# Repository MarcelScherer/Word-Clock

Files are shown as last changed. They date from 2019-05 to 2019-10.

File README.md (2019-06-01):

# Word-Clock with Android App for color changing (WIP)

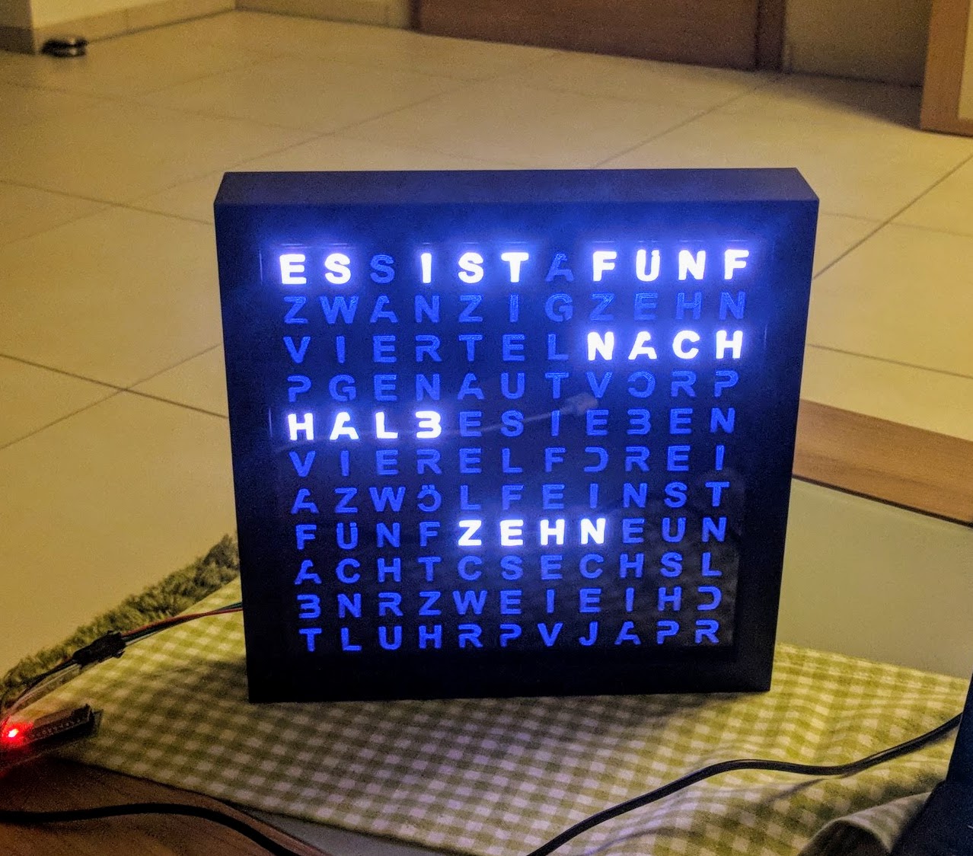
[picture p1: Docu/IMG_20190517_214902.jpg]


in addition, the following external sources are used in this project ... <br>
[NTPClinet for get actual time](https://github.com/arduino-libraries/NTPClient) <br>
[RTClib for offline function](https://github.com/adafruit/RTClib) <br>
[NeoPixelBus for control ws2812b strip](https://github.com/Makuna/NeoPixelBus) <br>
letterboxes.scad (I don't know the original link, sorry ...)

# Hardware

First you have to print the [STL files](https://github.com/MarcelScherer/Word-Clock/tree/master/Hardware) on a 3D printer. If you want to adjust the size, you can also create your own STL files with the help of the [script](https://github.com/MarcelScherer/Word-Clock/blob/master/Hardware/letterboxes.scad) and openSCAD. <br>
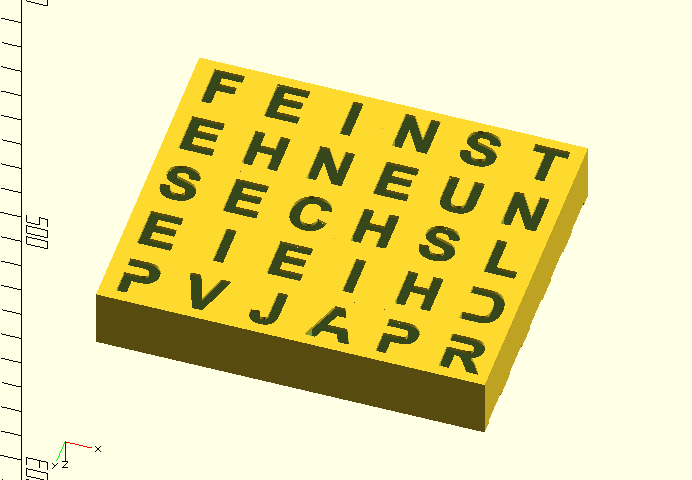
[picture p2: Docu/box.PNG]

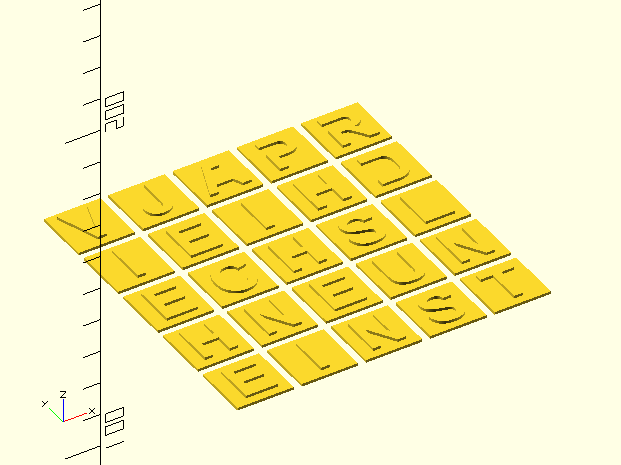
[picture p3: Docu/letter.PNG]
 <br>
<br>
After Printing the boxes and letters ... <br>
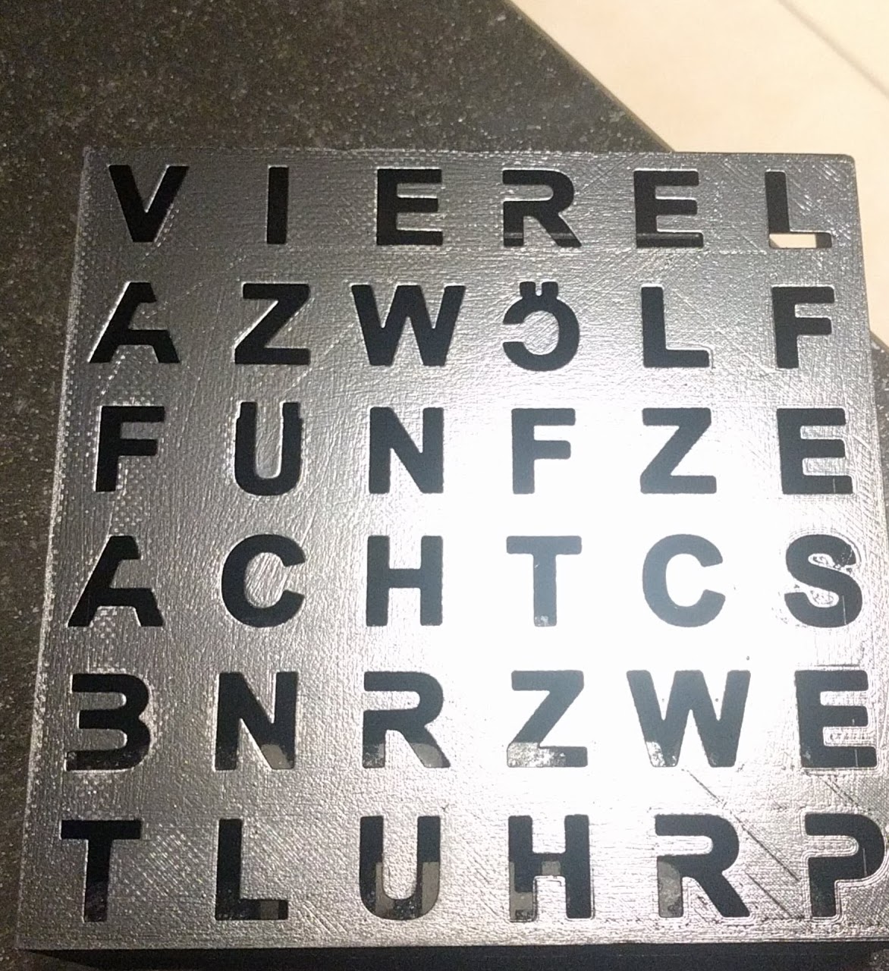
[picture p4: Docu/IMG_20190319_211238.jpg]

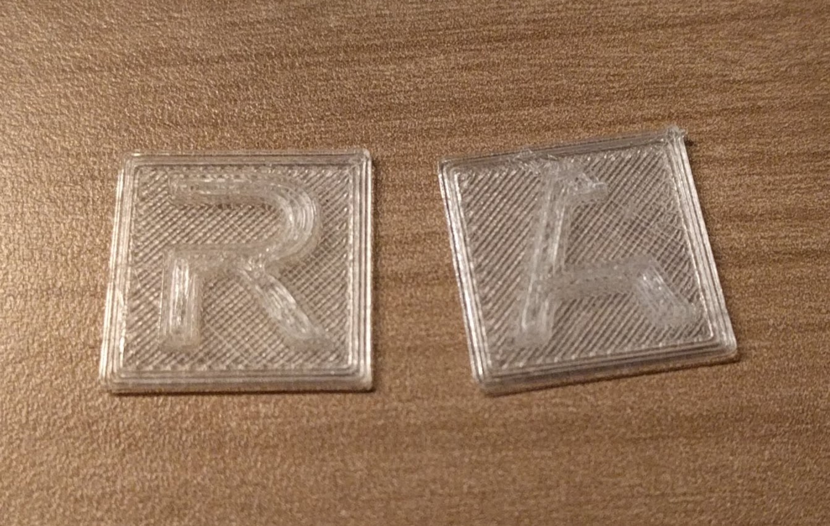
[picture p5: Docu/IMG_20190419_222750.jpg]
  <br>

... then you have to put the letters in the boxes.  <br>
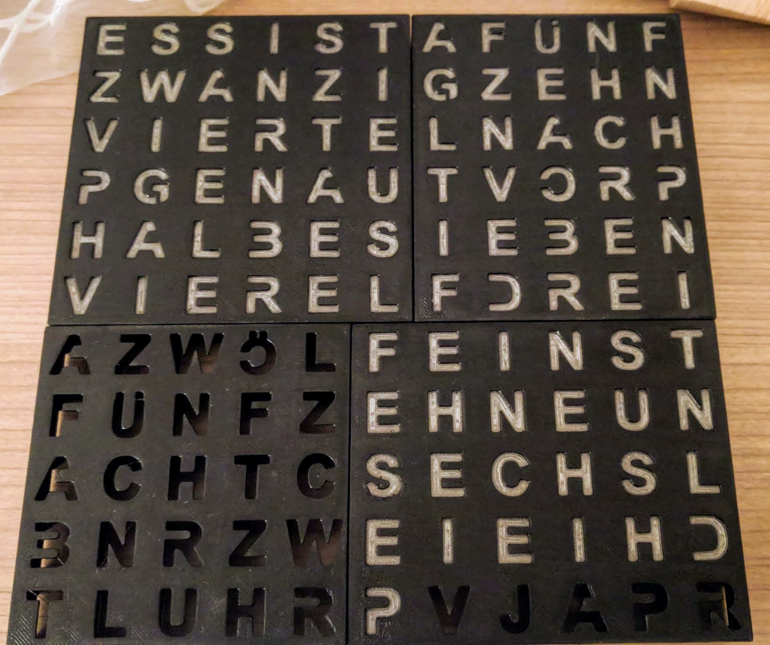
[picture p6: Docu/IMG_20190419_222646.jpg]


After that you have to fix the led ws2812b stripes ... <br>
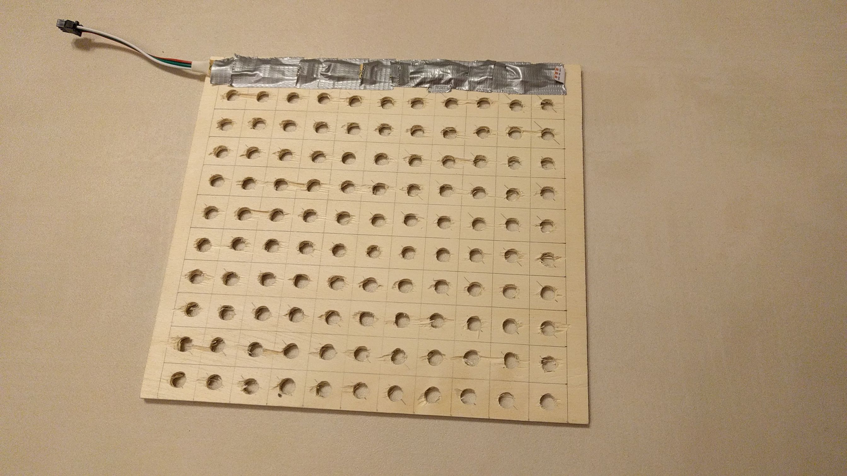
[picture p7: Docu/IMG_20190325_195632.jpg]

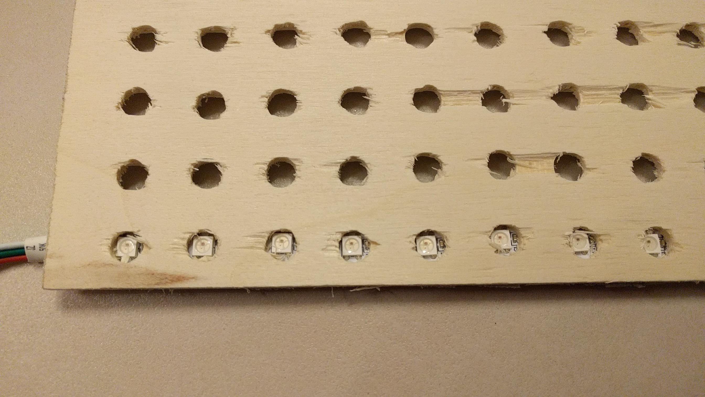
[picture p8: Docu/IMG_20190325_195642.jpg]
  <br>

# Software

You have to compile and flash the sorce (I do it with Visual Studio Code) an an ESP32. For ESP8266 you have to change small things like led pin, NeoPixelBus definition, and so on ...  You can change the pinning for the led-strip in the cfg.h file. I use the pinning ... <br>

| Pin | LED-Strip | Color | 
|---|:---:|---|
| P15 |  Led Pin | green |
| GND |  Ground | white |
| 5V |  Power Supply | red |

| Pin | RTC | Color | 
|---|:---:|---|
| P21 |  SDA | green |
| P22 |  Ground | yellow|
| 5V |  Power Supply | red |
| GND |  GND | blue  |

you can/shold config also in the cfg.h file ... <br>

| define | function | 
|---|---|
|INTERRUPT_PRESCALER | 1000.000 ticks per second |
| | depend on board |
|INTERRUPT_TICK | how many ticks to next interrupt |
|WIFIPWD | wifi password |
|WLAN_SSID | wifi ssid |
|UPDATE_TIME_VAL | ntc update time interval in hours |
|USE_RTC | if you use a RTC or not true/false |
|DEBUG | if you activate debug information |
| | over seral output true/false |
|LED_PIN | Pin for led strip |
|NUM_OF_PIXEL | number of led pixel 121 (11 * 11) |
|MAX_BRIGHTNESS_ON | muximum brightness for led's where on |
|MAX_BRIGHTNESS_OFF  | muximum brightness for led's where off|
|TIME_DISPLAY_OFF | time for display off |
|TIME_DISPLAY_ON | time for display on |

if TIME_DISPLAY_OFF and TIME_DISPLAY_ON are same, the leds are allways on <br>

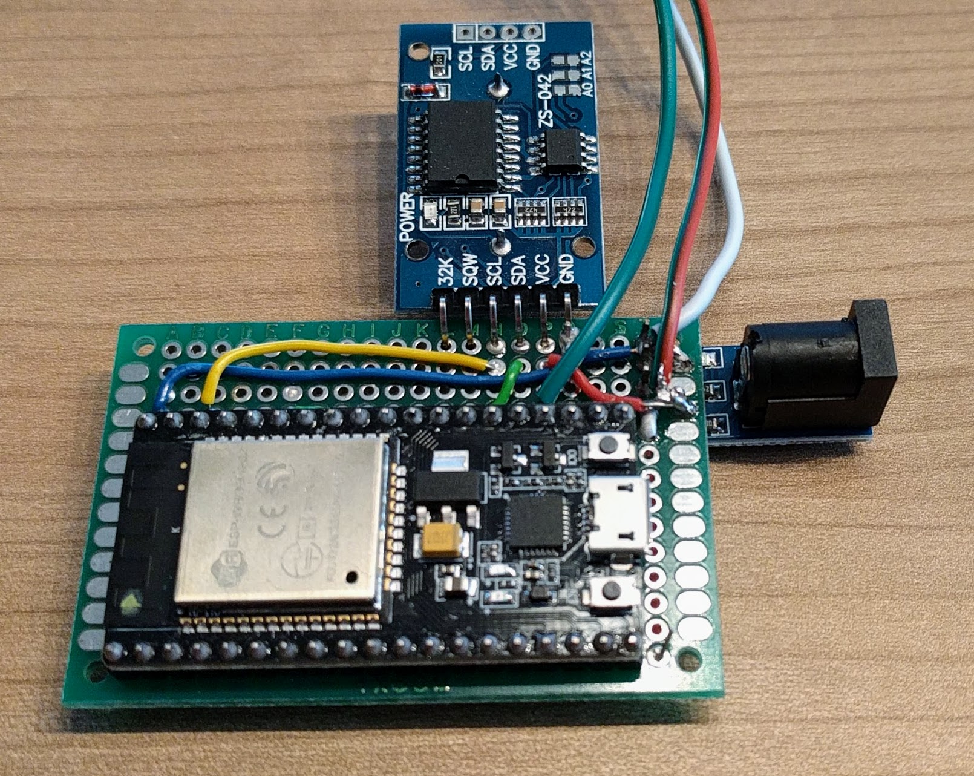
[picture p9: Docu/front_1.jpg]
 
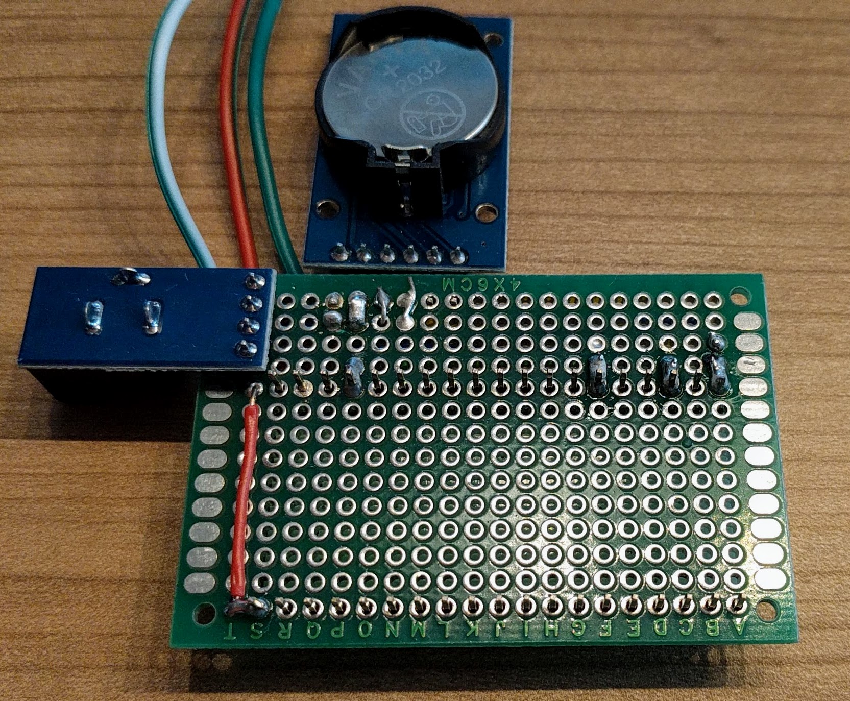
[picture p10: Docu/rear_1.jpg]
 

# Android App

The android app find the word-clock with the mDNS "Word_Clock.local". You can compile the [android procject](https://github.com/MarcelScherer/Word-Clock/tree/master/WordClockapp), or istall direct the [SDK](https://github.com/MarcelScherer/Word-Clock/blob/master/WordClockapp/app/build/outputs/apk/debug/app-debug.apk) <br>

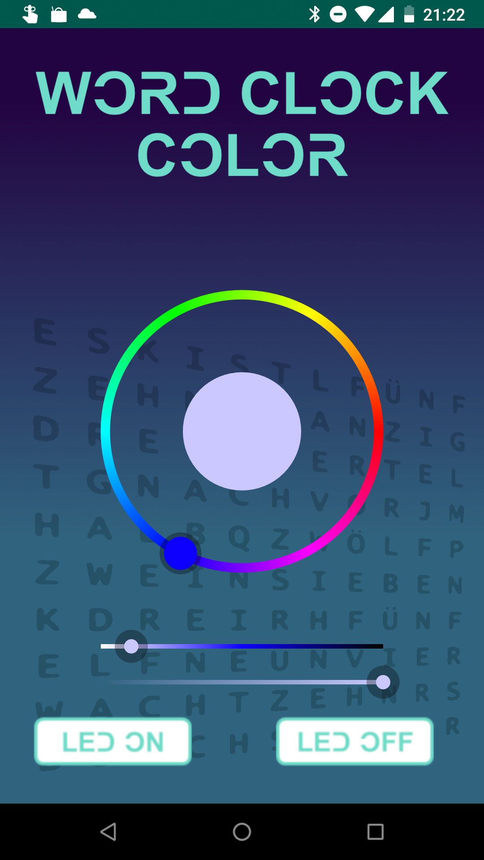
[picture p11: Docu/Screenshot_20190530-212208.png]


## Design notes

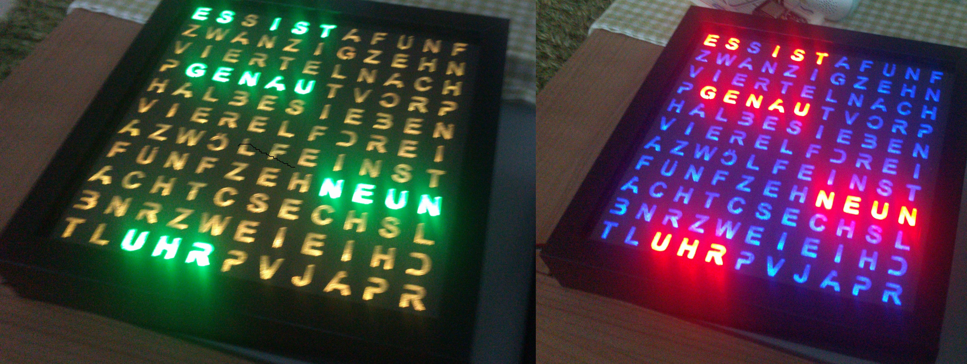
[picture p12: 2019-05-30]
Docu/IMG-20190525-WA0003.jpg

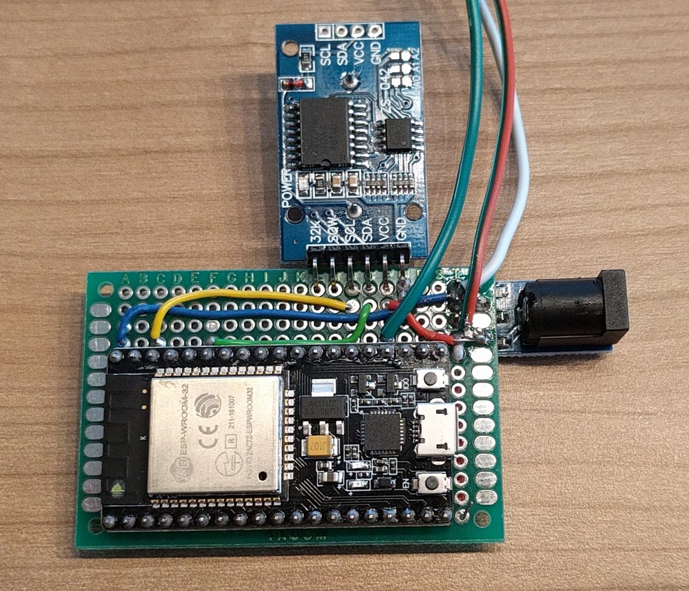
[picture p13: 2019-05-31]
Docu/front_2.jpg

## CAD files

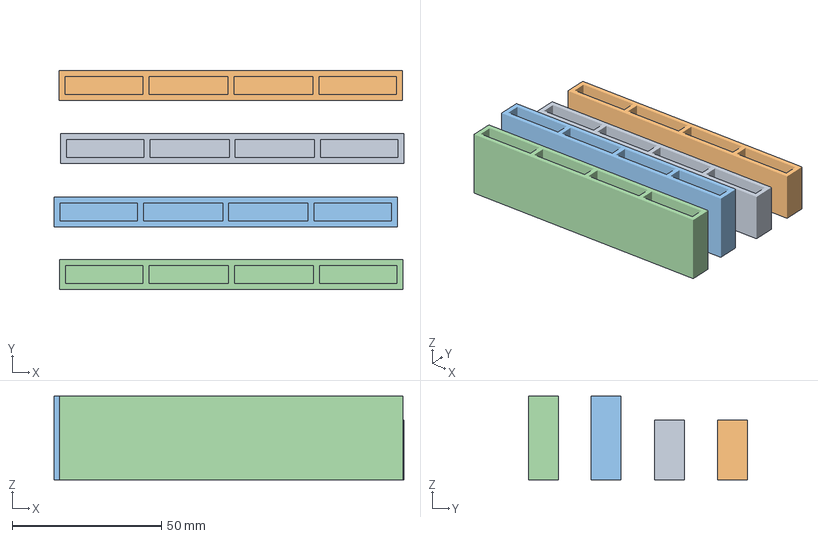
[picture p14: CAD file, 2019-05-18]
Hardware/CCR10_boddy.3mf
117.2 x 73.2 x 28.0 mm

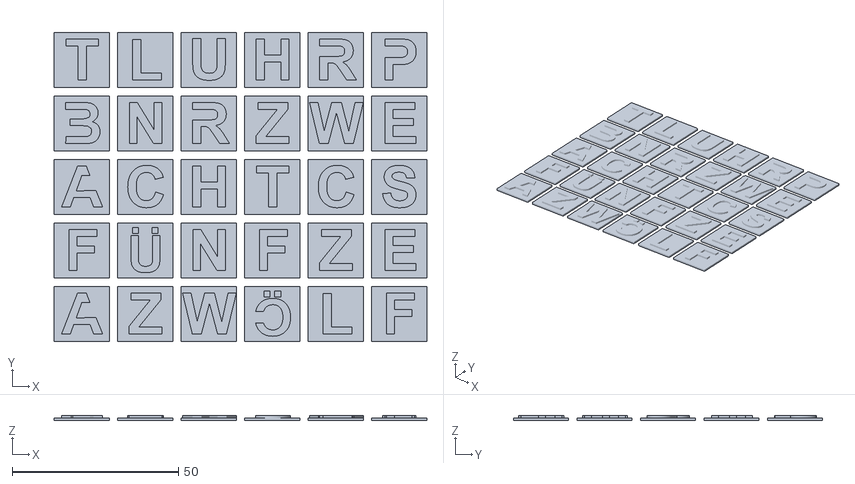
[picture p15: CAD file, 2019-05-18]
Hardware/letter_3.stl
112.1 x 93.0 x 1.62

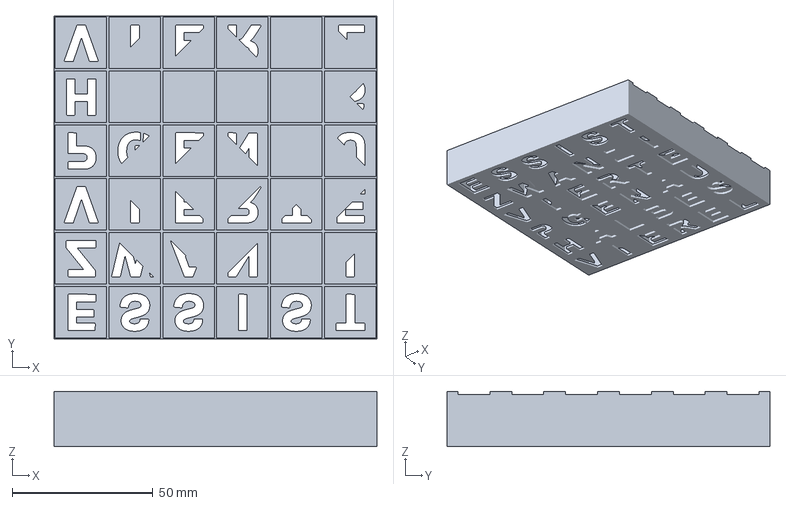
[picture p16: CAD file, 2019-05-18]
Hardware/CCR10_letterboxes_1.3mf
114.5 x 114.5 x 19.5 mm

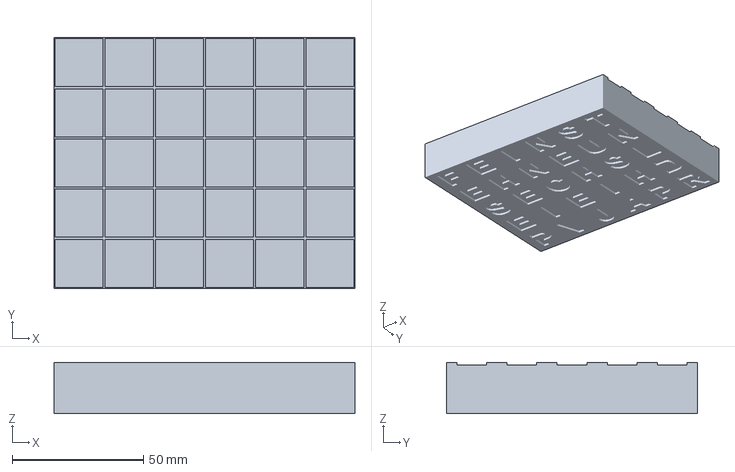
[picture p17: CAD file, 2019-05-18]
Hardware/CCR10_letterboxes_4.3mf
114.5 x 95.5 x 19.5 mm

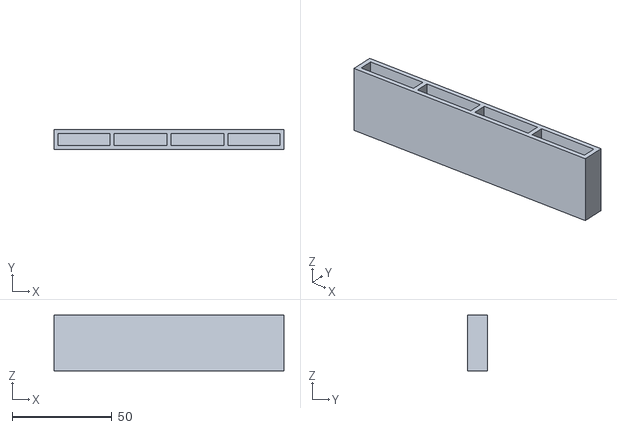
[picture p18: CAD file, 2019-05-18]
Hardware/boddy_2.stl
115.0 x 10.0 x 28.0

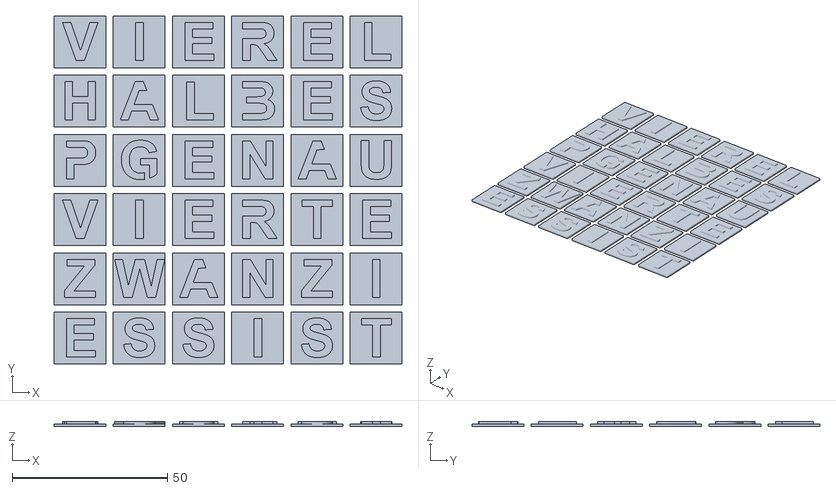
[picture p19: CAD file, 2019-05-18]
Hardware/letter_1.stl
112.1 x 112.1 x 1.62

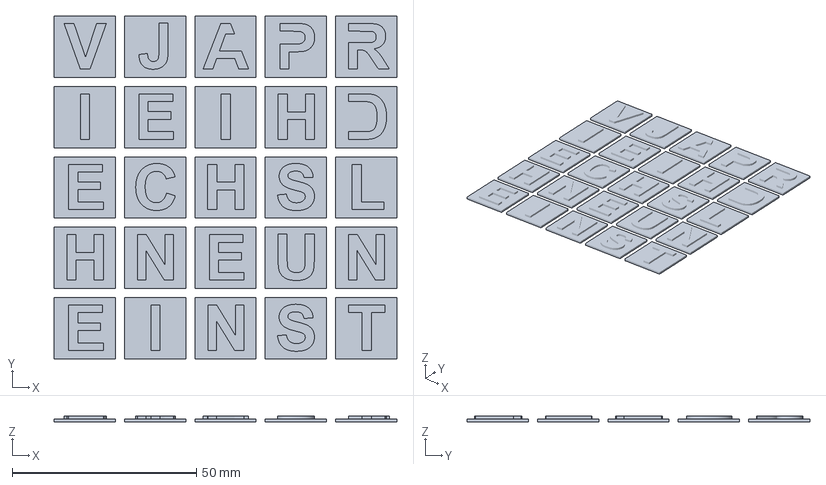
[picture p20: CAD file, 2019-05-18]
Hardware/CCR10_letter_4.3mf
93.0 x 93.0 x 1.62 mm

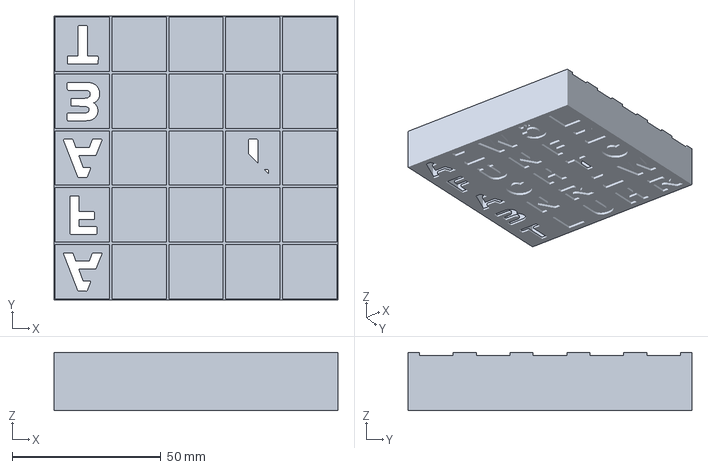
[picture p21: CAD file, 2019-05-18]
Hardware/CCR10_letterboxes_3.3mf
95.4 x 95.5 x 19.5 mm

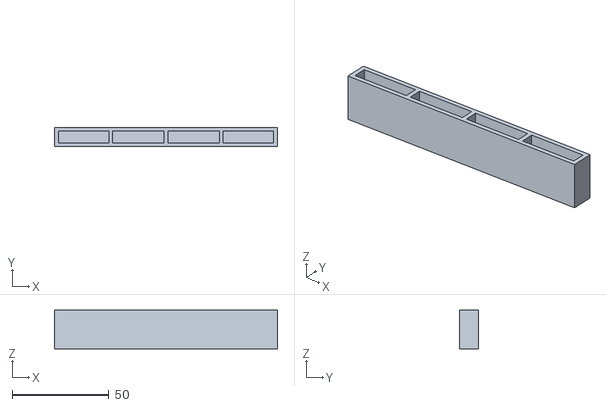
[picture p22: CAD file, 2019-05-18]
Hardware/boddy_1.stl
115.0 x 10.0 x 20.0

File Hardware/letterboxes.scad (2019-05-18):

$fn=500;

use <transformlib2d.scad>

//Parameters
thickness = 1.01;
width = 19.09;  
length = 19.09;
wall_thickness = 0.41;
height = 18.5; // total height = height + thickness -> only letterbox

thickness_letter_ground_plate = 0.81; // thickness of plate on which letter is printed
letter_overhang = 0.2; // letter thickness on top of letter ground plate

offset = 2; // offset for letter -> size reduction of letter ground plate

stripe_height = 1; // height of stripe -> only letterbox
stripe_width = 11; // width  of stripe -> only letterbox


component = "l"; //"l" = letter or "b" = box
letter = "Ü"; // if single letter (ALT + 0149 = •)

module Letter(letter, size=30, thickness) {

    if (letter == "Ü" || letter == "Ö" || letter == "Ä") {
        text(letter, 
             size=size*0.58, // size for ÖÄÜ
             font="Ender3:style=Regular", 
             halign="center",
             valign="center");
    }
    else {
        text(letter, 
             size=size*0.65, // size for all other letters than ÖÄÜ
             font="Ender3:style=Regular",
             halign="center",
             valign="center");
    }
 
}



module printletterbox(letter) {
 
    // outset = space between shape of letter at letterbox and letter
    linear_extrude(thickness) difference() {
        square([width, length], center=true);
        outset(d=0.3) Letter(letter, size=width);
       }
       
    translate([0, 0, -height/2]) //before z=-2*wall_thickness
    difference() {
        cube([width, length, height], center=true);
        cube([width-2*wall_thickness, length-2*wall_thickness, height], center=true);
        //the led stripe
        //translate([0, 0, -height/2+stripe_height/2]) cube([width, stripe_width, stripe_height], center=true);
    }

}


//color("red", 1) translate([0, 0, thickness]) linear_extrude(thickness + letter_overhang) Letter(letter, size=width);


module printletter(letter) {

    translate([0, 0, thickness]) 
        cube([width-wall_thickness-offset, length-wall_thickness-offset, thickness_letter_ground_plate], center=true);
    color("red", 1) translate([0, 0, thickness]) linear_extrude(thickness + letter_overhang) Letter(letter, size=width);
    
}



//connector

c_thickness = 0; // 0 = no connector 
c_len_y = wall_thickness*2 + c_thickness*2;
c_len_x = stripe_width + 0;
c_height = height/3;

module connectorClip() {
    
difference() {
    union() {
        cube([c_len_x, c_len_y, c_thickness]); //ground
        cube([c_len_x, c_thickness ,c_height]); //side1
        translate([0, c_len_y-c_thickness, 0]) cube([c_len_x, c_thickness ,c_height]); //side2
    }
    translate([(c_len_x-stripe_width)/2, 0, c_thickness]) cube([stripe_width, c_len_y, c_height]);
}

}



module LetterBoxWithConnectors2(top, right, bottom, left, letter) {
    rotate([180, 0, 0])
        difference() {
            printletterbox(letter);
            if (left) {
            translate([-width/2,0,c_thickness/2-height]) cube([c_len_y+0.3, c_len_x+0.3, c_thickness+1+stripe_height], center=true); //ground
            }
            if (right) {
            translate([width/2,0,c_thickness/2-height]) cube([c_len_y+0.3, c_len_x+0.3, c_thickness+1+stripe_height], center=true); //ground
            }
            if (top) {
            translate([0,width/2,c_thickness/2-height]) cube([c_len_x+0.3, c_len_y+0.3, 0], center=true); //ground
            }
            if (bottom) {
            translate([0,-width/2,c_thickness/2-height]) cube([c_len_x+0.3, c_len_y+0.3, 0], center=true); //ground
            }
    }
}


layout = [  ["E","S","S","I","S","T","A","F","Ü","N","F"],
            ["Z","W","A","N","Z","I","G","Z","E","H","N"],
            ["V","I","E","R","T","E","L","N","A","C","H"],
            ["P","G","E","N","A","U","T","V","O","R","P"],
            ["H","A","L","B","E","S","I","E","B","E","N"],
            ["V","I","E","R","E","L","F","D","R","E","I"],
            ["A","Z","W","Ö","L","F","E","I","N","S","T"],
            ["F","Ü","N","F","Z","E","H","N","E","U","N"],
            ["A","C","H","T","C","S","E","C","H","S","L"],
            ["B","N","R","Z","W","E","I","E","I","H","D"],
            ["T","L","U","H","R","P","V","J","A","P","R"],
];

if (component == "b") {
//    LetterBoxWithConnectors2(true, true, true, true, letter);
    for (r=[6:1:(11-1)]) {
        for (i =[5:1:(11-1)]) {
            translate([i*width, r*width, 0]) LetterBoxWithConnectors2(true, true, true, true, layout[r][i]);
        }
    }
}
else {
//    printletter(letter);
    for (r=[6:1:(11-1)]) {
        for (i =[6:1:(11-1)]) {
            translate([i*width, r*width, 0]) printletter(layout[r][i]);
        }
    }
}

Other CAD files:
Hardware/CCR10_letter_3.3mf
Hardware/letterboxes_4.stl
Hardware/CCR10_letter_2.3mf
Hardware/letter_2.stl
Hardware/letterboxes_1.stl
Hardware/CCR10_letter_1.3mf
Hardware/CCR10_letterboxes_2.3mf
Hardware/letter_4.stl
Hardware/letterboxes_2.stl
Hardware/transformlib2d.scad
Hardware/letterboxes_3.stl

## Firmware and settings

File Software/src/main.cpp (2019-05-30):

#include <Arduino.h>
#include "cfg.h"
#include "time_hdl/time_hdl.h"
#include <NeoPixelBus.h>
#include "word_array_hdl/word_array_hdl.h"
#include "color_store/color_store.h"


volatile int interruptCounter;
int totalInterruptCounter;
uint8_t update_hour;

led_col_t led_on  = {80, 80, 80};
led_col_t led_off = {0,   0,  5};

#define COLOR_OFF ( RgbColor(led_off.red, led_off.green, led_off.blue))
#define COLOR_ON  ( RgbColor(led_on.red,  led_on.green,  led_on.blue))

// Set web server port number to 80
WiFiServer server(80);

//NeoPixelBus<LED_STRIPE_TYP, NeoEsp32I2s1800KbpsMethod> strip(11*11, LED_PIN);
NeoPixelBus<NeoGrbFeature, Neo800KbpsMethod> strip(NUM_OF_PIXEL, LED_PIN);

hw_timer_t * timer = NULL;                                           /* pointer for interrupt */  
portMUX_TYPE timerMux = portMUX_INITIALIZER_UNLOCKED;                /* semaphore for interruptCounter */

 /* interrup function called by internal interrupt */
void IRAM_ATTR onTimer() {
  portENTER_CRITICAL_ISR(&timerMux);                                 /* lock semaphore */ 
  interruptCounter++;
  portEXIT_CRITICAL_ISR(&timerMux);                                  /* release semaphore */
}
 
 /* initialize */
void setup() {
  Serial.begin(115200);                                              /* start serial monitoring with 115.200 baut */ 

  time_hdl_initialize();
  init_eeporm();

    if(WiFi.status() == WL_CONNECTED)
    {
        server.begin();
    }

  strip.Begin();
  strip.Show();

  led_on = init_value_on();
  led_off = init_value_off();

  timer = timerBegin(0, INTERRUPT_PRESCALER, true);                 /* config interrupt register */
  timerAttachInterrupt(timer, &onTimer, true);                      /* function ponter for call by interrup */
  timerAlarmWrite(timer, INTERRUPT_TICK, true);                     /* set interrupt counter */
  timerAlarmEnable(timer);                                          /* enable interrup */
  update_hour = update_clock_time(0).hour;
}
 
void loop() {

  uint8_t ticks = 0;

  if (interruptCounter > 0) {                                        /* check if interrup was set */
 
    portENTER_CRITICAL(&timerMux);                                   /* lock semaphore */
    ticks = interruptCounter;                                              
    interruptCounter = 0;
    portEXIT_CRITICAL(&timerMux);                                    /* release semaphore */

    clock_time_t timer = update_clock_time(ticks);                   /* update actual time */
#ifdef DEBUG
    Serial.print(timer.hour);
    Serial.print(":");
    Serial.print(timer.minutes);
    Serial.print(":");
    Serial.println(timer.seconds);
#endif
    /* update time from internet or RTC */
    if((timer.hour - update_hour )%24 > UPDATE_TIME_VAL)            
    {
#ifdef DEBUG
    Serial.println("update time");
    Serial.print("update_hour:");
    Serial.println(update_hour);
    Serial.print("timer.hour:");
    Serial.println(timer.hour);
#endif
      /* update time from internet if wlan is available */
      if(check_wlan_conection())                                
      {
        timer = get_internet_time();
      }
      /* or update from RTC */
      else if(USE_RTC)
      {
        timer = get_rtc_time();
      }
      else
      {
        
      }
      update_hour = timer.hour;
    }

    /* update all pixels from pixel array*/
    if(check_if_display_on(timer))
    {
      uint8_t * p_pixel_array = create_word_array(timer);
      for(int8_t i=0; i<NUM_OF_PIXEL; i++)
      {
        if(p_pixel_array[i]  == 1)
        {
          strip.SetPixelColor(i, COLOR_ON);
        }
        else
        {
          strip.SetPixelColor(i, COLOR_OFF);
        }
        
      }
    }
    else
    {
      for(int8_t i=0; i<NUM_OF_PIXEL; i++)
      {
        strip.SetPixelColor(i, RgbColor(0, 0, 0));
      }
    }
    
    strip.Show();
  } /* end of second cycle*/

  WiFiClient client = server.available();   // Listen for incoming clients
  if (client)                               // If a new client connects,
  {
    Serial.println("New Client.");          // print a message out in the serial port
    String currentLine = "";                // make a String to hold incoming data from the client
    while (client.connected())              // loop while the client's connected
    {
      if (client.available() >= 5)           // if there's bytes to read from the client,
      {
        uint8_t data_dump[5];
        std::fill_n(data_dump, sizeof(data_dump), 0);  // fill array with zeros

        Serial.print("datadump: "); 
        for(uint8_t k = 0; k<5; k++)
        {
          data_dump[k] = client.read(); 
#ifdef DEBUG
          Serial.print("Data dump: ");
          Serial.println(data_dump[k]); 
#endif
        }

        if(data_dump[4] == 1)
        {
          led_on.red = (uint8_t)((float)(data_dump[1])*(float)(data_dump[0])
                       /((float)(0xFF)*((float)(0xFF)/(float)(MAX_BRIGHTNESS_ON)) ));
          led_on.green = (uint8_t)((float)(data_dump[2])*(float)(data_dump[0])
                       /((float)(0xFF)*((float)(0xFF)/(float)(MAX_BRIGHTNESS_ON)) ));
          led_on.blue = (uint8_t)((float)(data_dump[3])*(float)(data_dump[0])
                       /((float)(0xFF)*((float)(0xFF)/(float)(MAX_BRIGHTNESS_ON)) ));

          set_value_on(led_on);
#ifdef DEBUG
          Serial.print("Color ON:"); Serial.print(led_on.red); Serial.print(" ");
          Serial.print(led_on.green); Serial.print(" "); Serial.println(led_on.blue); 
#endif
        }
        else if(data_dump[4] == 2)
        {      
          led_off.red = (uint8_t)((float)(data_dump[1])*(float)(data_dump[0])
                       /((float)(0xFF)*((float)(0xFF)/(float)(MAX_BRIGHTNESS_OFF)) ));
          led_off.green = (uint8_t)((float)(data_dump[2])*(float)(data_dump[0])
                       /((float)(0xFF)*((float)(0xFF)/(float)(MAX_BRIGHTNESS_OFF)) ));
          led_off.blue = (uint8_t)((float)(data_dump[3])*(float)(data_dump[0])
                       /((float)(0xFF)*((float)(0xFF)/(float)(MAX_BRIGHTNESS_OFF)) ));

          set_value_off(led_off);
#ifdef DEBUG
          Serial.print("Color OFF:"); Serial.print(led_off.red); Serial.print(" ");
          Serial.print(led_off.green); Serial.print(" "); Serial.println(led_off.blue); 
#endif
        }
        else
        {
          Serial.println("wring data dump");
          strip.SetPixelColor(0, RgbColor(100, 0, 0));
          strip.Show();
        }
        client.flush();
        client.stop();
      }
    }
  }
}

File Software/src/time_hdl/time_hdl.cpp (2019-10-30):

#include "time_hdl.h"
#include "../cfg.h"
#include <string.h>
#include <RTClib.h>
#include <ESPmDNS.h>

static void set_clock_timer(void);
int8_t summertime_EU_offest(int year, byte month, byte day, byte hour, byte tzHours);

/* wlan connection */
const char* ssid     = WLAN_SSID;                             
const char* password = WIFIPWD; 

/* rtc object */
static RTC_DS3231 rtc;

// Define NTP Client to get time
WiFiUDP ntpUDP;
NTPClient timeClient(ntpUDP);

clock_time_t clock_time;

void time_hdl_initialize(void)
{
    uint8_t wlan_init_count = 0;

    pinMode(SUMMER_TIME_PIN, INPUT);                                    // sets the digital pin for summer time switch as input

    WiFi.begin(ssid, password);                                         // set ssid and password
    while (    (WiFi.status() != WL_CONNECTED)                          // while wlan not connected
            && (wlan_init_count < 20))
    {
        if(USE_RTC)
        {
            wlan_init_count++;                                          // increment timer for wlan time out
        }
        delay(500);                                                     // wait 0.5 seconds for wlan connection
#ifdef DEBUG                                                         
        Serial.print(".");                                              // print "."
#endif
    }
#ifdef DEBUG 
    Serial.println(".");
    Serial.print("IP address: ");                                      // print local ip
    Serial.println(WiFi.localIP());
#endif

    if(USE_RTC)
    {
        /* init rtc module */
        if (! rtc.begin()) {                                           // try to connect to rtc
            Serial.println("Couldn't find RTC");
            while (1);
        }
        else
        {
    #ifdef DEBUG
            Serial.println("RTC found");
    #endif   
        }
    }

    if((WiFi.status() == WL_CONNECTED))                                 /* if wlan is connected ... */
    {
        // Initialize a NTPClient to get time
        timeClient.begin();                                             /* Initialize NTP clinet ... */
        timeClient.setTimeOffset(3600);                                 /* ... set time offset ... */
        timeClient.forceUpdate();                                       /* ... and read time from internet */
        set_clock_timer();                                              /* ... convert internet time to clock_time */
        set_rtc_date_time(clock_time, 2018, 1, 1);                      /* write actual time in rtc clock */

        if (!MDNS.begin("Word_Clock")) 
        {
#ifdef DEBUG 
            Serial.println("Error setting up MDNS responder!");
#endif 
        }
#ifdef DEBUG 
        Serial.println(timeClient.getFormattedTime());
#endif 
    }        
    else                                                                /* if wlan is not connected ... */
    {
        clock_time = get_rtc_time();                                    /* reat time from rtc clock */
    }

}

/* convert ntc time to clock_time */
static void set_clock_timer(void)
{
    if(!digitalRead(SUMMER_TIME_PIN))
    {
        clock_time.hour    = timeClient.getHours();                     // winter time
#ifdef DEBUG 
        Serial.println("winter time");
#endif 
    }
    else
    {
        clock_time.hour    = timeClient.getHours() + 1;                 // summer time
#ifdef DEBUG 
        Serial.println("summer time");
#endif 
    }
    clock_time.minutes = timeClient.getMinutes();
    clock_time.seconds = timeClient.getSeconds();
}

bool check_wlan_conection(void)
{
    uint8_t count = 0;

    if(WiFi.status() != WL_CONNECTED)                                   /* if wlan not connected */
    {
        WiFi.begin(ssid, password);                                     /* try to connect */
    }

    if(    (WiFi.status() != WL_CONNECTED)                              /* wait for connection */
        || count >= 20)
    {
        delay(500); 
    }

    return (WiFi.status() == WL_CONNECTED);                             /* return internet status connectet = true */
}

/* update time */
clock_time_t update_clock_time(uint8_t ticks)
{ 
    uint8_t seconds = clock_time.seconds + ticks;                       /* add seconds and look that not over 59 */
    clock_time.seconds = seconds % 60;

    uint8_t minutes = clock_time.minutes + seconds / 60;                /* add minutes and look that not over 59 */
    clock_time.minutes = minutes % 60;

    uint8_t hour = clock_time.hour + minutes / 60;                      /* add hours and look that not over 23 */
    clock_time.hour = hour % 24;

    return clock_time;                                                  /* return new clock_time */
}

/* write time and date to rtc clock */
void set_rtc_date_time(clock_time_t time, uint16_t year, uint8_t month, uint8_t day )
{
#ifdef DEBUG 
        Serial.print("set RTC time: ");
        Serial.print(time.hour);
        Serial.print(":");
        Serial.print(time.minutes);
        Serial.print(":");
        Serial.println(time.seconds);
#endif
    rtc.adjust(DateTime(year, month, day, time.hour, time.minutes, time.seconds));
}

/* get time from rtc clock */
clock_time_t get_rtc_time(void)
{
    clock_time_t temp_time;
    DateTime now = rtc.now();                                           /* reat time from rtc clock ... */

    temp_time.hour    = now.hour();                                     /* ... and convert to clock_time */
    temp_time.minutes = now.minute();
    temp_time.seconds = now.second();

#ifdef DEBUG 
        Serial.print("get RTC time: ");
        Serial.print(temp_time.hour);
        Serial.print(":");
        Serial.print(temp_time.minutes);
        Serial.print(":");
        Serial.println(temp_time.seconds);
#endif
    return temp_time;                                                   /* return clock_time from rtc clock */
}

/* get time from internet ntp */
clock_time_t get_internet_time(void)
{
    timeClient.forceUpdate();                                           /* reat time from internet ntp server */
    set_clock_timer();                                                  /* convert ntp time to clock_time */
    return clock_time;                                                  /* retunr clock_time form ntp server*/
}
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

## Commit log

2019-05-18 add sorce
    [CCR10_boddy.3mf, CCR10_letter_1.3mf, CCR10_letter_2.3mf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]
2019-05-20 Bugfix Pixel
    bugfix some errors to show the correct time
    [main.cpp]
